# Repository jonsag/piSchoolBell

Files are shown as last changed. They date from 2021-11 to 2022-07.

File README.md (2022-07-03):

# piSchoolBell

This runs a Raspberry Pi as a controller for a school bell.  
It makes the school bell ring at the right times taking the calendar into consideration.  
Also there is an LCD screen to visualize time, database stats, upcoming rings etc.  

Administration of the school bell is done via a web UI.  

It is written entirely in python.  

Also it installs gpio-watch to catch the buttons connected to the Pi's GPIO. [https://github.com/larsks/gpio-watch](https://github.com/larsks/gpio-watch)  

## Updates

### 3/7 -22

Now running on RaspberryPiOS Bullseye.  
Everything updated to run on python3.  
Updated install script.  
Made it easier for those not having the Swedish holidays. (More work needed...)  
New module for printing to LCD.  
Fixed apache not defaulting to index.py.  

### 30/6 -22

The API for Swedish holidays, api.dryg.net, is dead.  
Substituted by [sholiday.faboul.se](https://sholiday.faboul.se/dagar/).  

### 7/3 -20

Changed all GPIO pins to make an easier PCB layout possible.  
This makes all older electric installs incompatible.  
Added KiCad files for new pin layout.  

Corrected editing of ring times.  

### 6/3 -20

Bug discovered  
There was a fault in the database setup.  
Instead of updating, you can:  
Log in to database  
>$ sudo mysql -u root -p piSchoolBell  

Change column type  
>MariaDB [piSchoolBell]> ALTER TABLE ringTimes CHANGE weekDays weekDays VARCHAR(7);  

## Hardware setup

### Parts list

* 1 x Raspberry Pi 3 B+, kjell.com Art#88100 (could be any of the later models)  
* 1 x LCD display, kjell.com Art#90215 (16x2 characters, based on the HD44780 chip)  
* 1 x USB micro power adapter, kjell.com Art#88525  
* 1 x Micro SD card, kjell.com Art#97600  
* 1 x 10k potentiometer, kjell.com Art#90633  
* 1 x 5V relay module, kjell.com Art#87878  
* 4 x Push button, kjell.com Art#36023  
* 4 x 10k resistor  
* 4 x 1k resistor  
* 1 x Switch, kjell.com Art#36016  
* 1 x Casing for rpi, kjell.com Art#89030  
* 1 x Casing for relay, kjell.com Art#89014  
* 1 x RTC-module, kjell.com Art#87984  
* 1 x CR2032 battery, kjell.com ART#33715  
* GPIO header connector, kjell.com Art#87915 (or breakout board)  
* Wiring, cables  
* PCB board, kjell.com Art#89416 or Art#89435 (or a breadboard, just to set it up)  

* Soldering material  

### The build  

Assemble all the parts according to the KiCad files.  

### Install and configure OS

Download RaspberryPiOS Lite from [https://www.raspberrypi.com/software/operating-systems/](https://www.raspberrypi.com/software/operating-systems/).  

Cd to where your download is.  
>$ xz -d 2022-04-04-raspios-bullseye-armhf-lite.img.xz  

Insert SD-card and find out drive letter.  
>$ dmesg  

For example '/dev/mmcblk0' or '/dev/sdb'.  

Unmount if mounted.  
>$ umount /dev/mmcblk0p1  
>$ umount /dev/mmcblk0p2  

Write image to SD-card.  
>$ sudo dd bs=4M if=2022-04-04-raspios-bullseye-armhf-lite.img of=/dev/mmcblk0 conv=fsync status=progress  

Remove SD-card and insert it again to make new partitions visible.  

Mount the first partition.  
>$ sudo mount /dev/mmcblk0p1 /mnt/tmp  

Write empty file to boot partition to enable ssh at boot.  
>$ sudo touch /mnt/tmp/ssh  

Unmount.  
>$ sudo umount /mnt/tmp  

Remove SD-card and insert it in a RPi connected to your local network and boot it up.  

### RPi configuration

For this version of the operating system you should have a monitor and keyboard hooked up at the first boot.  

After some restarts you will start to configure your machine:

* Select keyboard layout  
* Create user and set password. For the sake of this installation it's preferred you set 'pi' as username.  

After this you will have a prompt.  
Find out the ip of the RPi

>$ ifconfig

Connect to the RPi via ssh on another machine (if you don't want to continue as before).  

>$ ssh -ip from above-  -l pi  

Login with the username and password you created earlier  

### Configure

>$ sudo raspi-config  

1 S1    Configure wifi  
2 S4    Change hostname  
4 P2    Set GPU memory to 16  
5 L1    Set locales  
5 L2    Set time zone  
6 A1    Expand file system to use whole SD-card  

Reboot to set new options.  

### Update OS

Connect again  

>$ sudo apt-get update && sudo apt-get upgrade  

## Installation

### Install git

>$ sudo apt-get install git  

### Clone repository

>$ cd /home/pi  
>$ git clone <https://github.com/jonsag/piSchoolBell.git>  

### Run install script

>$ cd /home/pi/piSchoolBell  
>$ sudo ./install.sh  

### Initialize mysql (mariadb)

>$ sudo mysql_secure_installation  

Set root password, and press 'enter' on all other questions

### Create database

>$ sudo /home/pi/piSchoolBell/mysql-setup.sh  

### Add test data, if wanted (otherwise some things will act funny until you create your own entries)  

>$ /home/pi/piSchoolBell/insertTestData.sh  

### Download (Swedish) dates

>$ /home/pi/bin/piSchoolBell/getCalendar.py -v  

### For those living outside of Sweden

If you're not lucky enough to live in Sweden, you can run this to make all weekdays workdays.  

>$ /home/pi/piSchoolBell/makeAllWeekdaysToWorkdays.sh

This includes ALL Mondays to Fridays.  

You will have to manually add your own work free weekdays.  

To set 4'th of July 2023 to work free day (if it wasn't a Sunday already...)  
Connect to mysql  

>$ mysql -u pi -p$(grep password /home/pi/bin/piSchoolBell/mysql-config.ini | awk '{ print $3 }') piSchoolBell
>
>MariaDB [piSchoolBell]> UPDATE days SET isWorkDay = '0' WHERE date = '2023-06-04';

#### Note

In Sweden we use the correct way for dates and numbering days.  

The first day of the week is Monday. It has number '0' in the database.  
When printing dates we use 'YYYY-MM-DD'.  

### Make web pages secure

>$ sudo /home/pi/piSchoolBell/www-secure-setup.sh  

## If you're adding an RTC module

### Enable i2c

>$ sudo raspi-config  

3 I5    Enable I2C interface  

>$ ./install-rtc.sh  

### Set hardware clock

Check that time and date is correct  

>$ date  

Set hardware clock  

>$ sudo hwclock -w  

Comment out the following lines in /lib/udev/hwclock-set  

    if [ -e /run/systemd/system ] ; then  
        exit 0  
    fi  

Reboot  

## Configuration

Press button on unit to display its IP-address on the second line of the LCD.  
Connect to the unit by pointing your browser to  

    http://\<IP-address\>:8080'.  

Edit or add breaks, ring times and ring patterns.  

Remember, you can't really add rings on saturdays or sundays, as this is mainly intended for use on normal school schedules.  

### Automatic tasks

At the first of every month cron will download calendar from 'dryg.net', adding data to the database.  
Every night cron will delete past breaks and days from the database.  

## Usage

Normally the LCD display shows:  
Line 1: HH:MM YYYY-mm-dd, current time and date  
Line 2: HH:MM YYYY-mm-dd, the time and date for the next bell ring  

By pressing button 1, display will show:  
&nbsp;&nbsp;&nbsp;&nbsp;Line 1: days left in db, last date in db  
&nbsp;&nbsp;&nbsp;&nbsp;Line 2: IP-address  
&nbsp;&nbsp;&nbsp;&nbsp;&nbsp;&nbsp;&nbsp;&nbsp;If it shows 'Not connected' it has not been able to acquire an IP address.  
&nbsp;&nbsp;&nbsp;&nbsp;&nbsp;&nbsp;&nbsp;&nbsp;The first character on line 2 shows if the unit can access internet.  
&nbsp;&nbsp;&nbsp;&nbsp;&nbsp;&nbsp;&nbsp;&nbsp;If it is a '*' it is connected.  
&nbsp;&nbsp;&nbsp;&nbsp;&nbsp;&nbsp;&nbsp;&nbsp;If it is a '-' it is not connected.  

Pressing button 2 will make the LCD go back to showing default info.  

## USE THE BELOW WITH CAUTION, NOT TESTED ENOUGH

To dump database and logs to USB-stick:  
Format a stick to fat32 and label it 'PISCHOOLBEL'.  
Insert into Pi.  
&nbsp;&nbsp;&nbsp;&nbsp;Display will show:  
&nbsp;&nbsp;&nbsp;&nbsp;&nbsp;&nbsp;&nbsp;&nbsp;The USBs label and drive letter  
&nbsp;&nbsp;&nbsp;&nbsp;&nbsp;&nbsp;&nbsp;&nbsp;'USB mounted'  
Press button 3.  
&nbsp;&nbsp;&nbsp;&nbsp;Display will confirm writing  
&nbsp;&nbsp;&nbsp;&nbsp;When finished display shows number of files written  

Remove USB  
&nbsp;&nbsp;&nbsp;&nbsp;Display will show:  
&nbsp;&nbsp;&nbsp;&nbsp;&nbsp;&nbsp;&nbsp;&nbsp;drive letter  
&nbsp;&nbsp;&nbsp;&nbsp;&nbsp;&nbsp;&nbsp;&nbsp;'USB umounted'  

Edit the database file with the highest date and time on the stick.  
To read back edited file to database:  
Insert the USB-stick.  
&nbsp;&nbsp;&nbsp;&nbsp;Display will show:  
&nbsp;&nbsp;&nbsp;&nbsp;&nbsp;&nbsp;&nbsp;&nbsp;The USBs label and drive letter  
&nbsp;&nbsp;&nbsp;&nbsp;&nbsp;&nbsp;&nbsp;&nbsp;'USB mounted'  
Press button 4.  
&nbsp;&nbsp;&nbsp;&nbsp;Display will confirm reading  
&nbsp;&nbsp;&nbsp;&nbsp;...  
Not implemented yet.  
For now it only shows how many lines to read back to the database.  

## Issues

If you get problems with Adafruit_Python_CharLCD failing to write to LCD.  

>$ cd /home/pi/piSchoolBell/Adafruit_Python_CharLCD  
>$ sudo python setup.py install  

## Hardware clock / RTC, quick reference

Check system time:  

>$ date  

Check HW-time:  

>$ sudo hwclock -r  

Set HW-clock to system time:  

>$ sudo hwclock -w  

Set system clock from HW-clock:  

>$ sudo hwclock -s  

Set system date manually:  

>$ date +%Y%m%d -s "20120418"  

Set system time manually:  

>$ date +%T -s "11:14:00"  

Set HW-clock manually:  

>$ sudo hwclock --set --date="2011-08-14 16:45:05"  

## Below is only for my own convenience during programming of this project

>$ rsync -raci ~/Documents/EclipseWorkspace/piSchoolBell/* pi@192.168.10.44:/home/pi/bin/piSchoolBell/  
>$ rsync -raci ~/Documents/EclipseWorkspace/piSchoolBell/www/* pi@192.168.10.44:/var/www/piSchoolBell/  
>$ ssh pi@192.168.10.44 'sudo chmod 755 -R /var/www/piSchoolBell'  
>$ ssh pi@192.168.10.44 'sudo chown -R pi:www-data /var/www/piSchoolBell'  
>$ rsync -raci ~/Documents/EclipseWorkspace/piSchoolBell/purgeDatabase.py pi@192.168.10.44:/home/pi/bin/piSchoolBell/  
>
>$ rsync -raci ~/Documents/CodeWorkspace/piSchoolBell pi@192.168.10.99:/home/pi/  
>$ rsync -raci ~/Documents/CodeWorkspace/piSchoolBell/bin/* pi@192.168.10.99:/home/pi/bin/piSchoolBell  

### Things to check after install

>$ list /home/pi/bin/piSchoolBell/  
>$ cat /home/pi/bin/piSchoolBell/gpio.service  
>$ cat /lib/systemd/system/gpio.service  
>$ list /home/pi/bin/piSchoolBell/gpio-scripts  
>$ cat /home/pi/bin/piSchoolBell/gpio-scripts/gpio-script  
>$ list /var/www/piSchoolBell  
>$ cat etc/cron.d/piSchoolBell  
>$ ps ax | grep gpio  

### Run some tests

>$ /home/pi/bin/piSchoolBell/printToLcd.py -v  
>$ i2cdetect -y 1  
>$ cat /proc/driver/rtc

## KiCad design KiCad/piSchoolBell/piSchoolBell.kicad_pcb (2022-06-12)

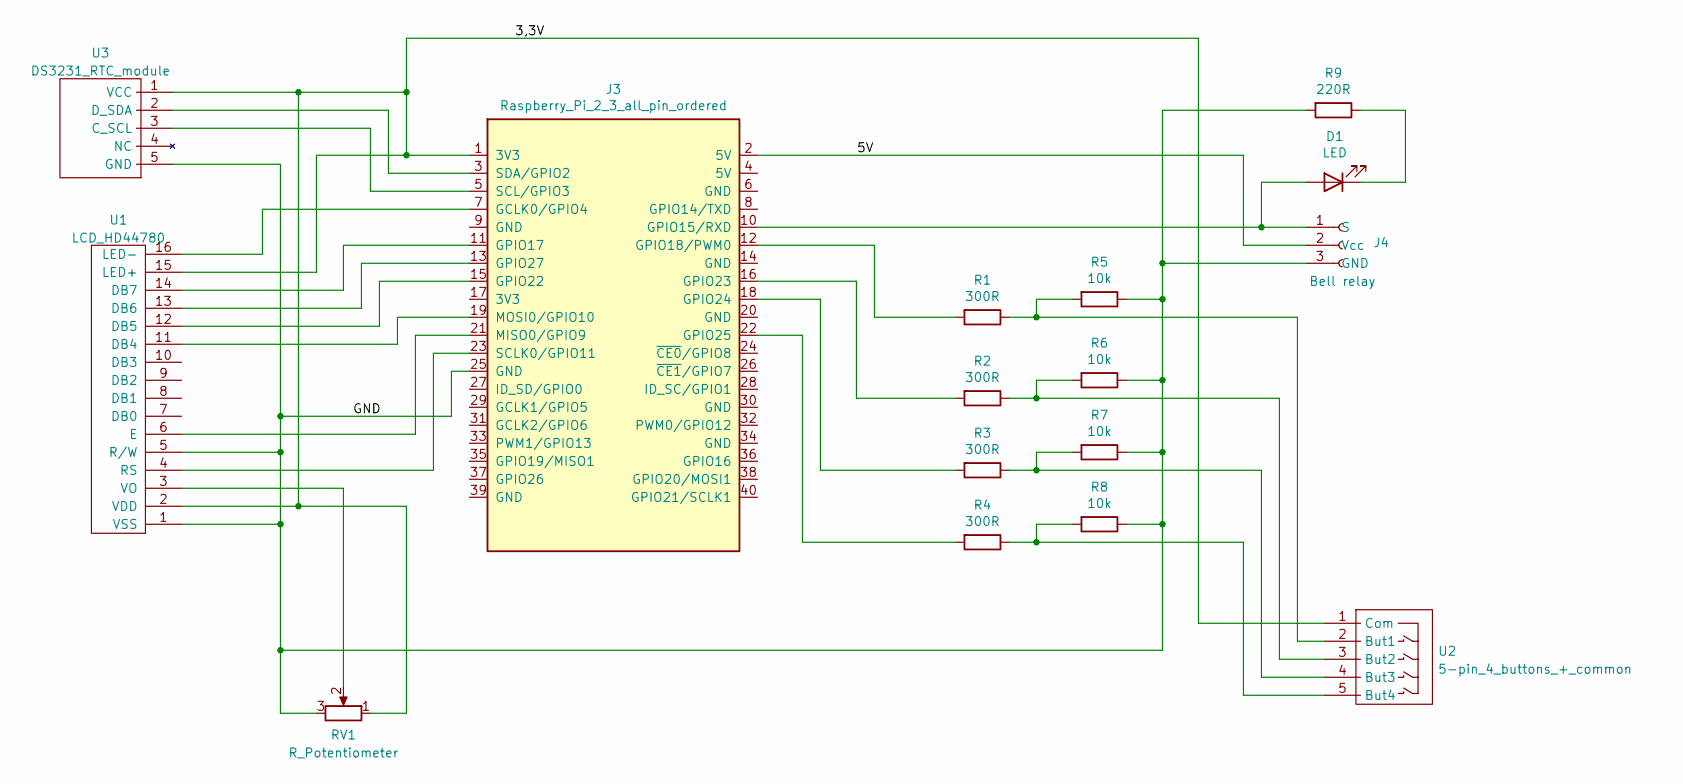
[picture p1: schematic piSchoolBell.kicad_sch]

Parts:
D1: LED; LED_D5.0mm_larger_pads
J3: Raspberry_Pi_2_3_all_pin_ordered; RaspberryPi_3b+_Hat_large
J4: Bell relay; 3-pin JST KY-019 relay
R1, R2, R3, R4: 300R; R_Axial_DIN0207_L6.3mm_D2.5mm_P10.16mm_Horizontal_larger_pa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
R5, R6, R7, R8: 10k; R_Axial_DIN0207_L6.3mm_D2.5mm_P10.16mm_Horizontal_larger_pa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
R9: 220R; R_Axial_DIN0207_L6.3mm_D2.5mm_P10.16mm_Horizontal_larger_pa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
RV1: R_Potentiometer; Potentiometer_Bourns_3339P_Vertical_large
U1: LCD_HD44780; LCD_HD44780_16x2_w_headers_large
U2: 5-pin_4_buttons_+_common; 5-pin JST 4 buttons + common
U3: DS3231_RTC_module; DS3231_RTC_module_large

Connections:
/3,3V: J3.1 (3V3), RV1.1, U1.2 (VDD), U1.15 (LED+), U2.1 (Com), U3.1 (VCC)
/5V: J3.2 (5V), J4.2 (Vcc)
/GND: J3.25 (GND), J4.3 (GND), R5.1, R6.1, R7.1, R8.1, R9.2, RV1.3, U1.1 (VSS), U1.5 (R/W), U3.5 (GND)
unnamed: D1.1 (K), R9.1
unnamed: D1.2 (A), J3.10 (GPIO15/RXD), J4.1 (S)
unnamed: J3.3 (SDA/GPIO2), U3.2 (D_SDA)
unnamed: J3.5 (SCL/GPIO3), U3.3 (C_SCL)
unnamed: J3.7 (GCLK0/GPIO4), U1.16 (LED-)
unnamed: J3.11 (GPIO17), U1.14 (DB7)
unnamed: J3.12 (GPIO18/PWM0), R1.2
unnamed: J3.13 (GPIO27), U1.13 (DB6)
unnamed: J3.15 (GPIO22), U1.12 (DB5)
unnamed: J3.16 (GPIO23), R2.2
unnamed: J3.18 (GPIO24), R3.2
unnamed: J3.19 (MOSI0/GPIO10), U1.11 (DB4)
unnamed: J3.21 (MISO0/GPIO9), U1.6 (E)
unnamed: J3.22 (GPIO25), R4.2
unnamed: J3.23 (SCLK0/GPIO11), U1.4 (RS)
unnamed: R1.1, R5.2, U2.2 (But1)
unnamed: R2.1, R6.2, U2.3 (But2)
unnamed: R3.1, R7.2, U2.4 (But3)
unnamed: R4.1, R8.2, U2.5 (But4)
unnamed: RV1.2, U1.3 (VO)

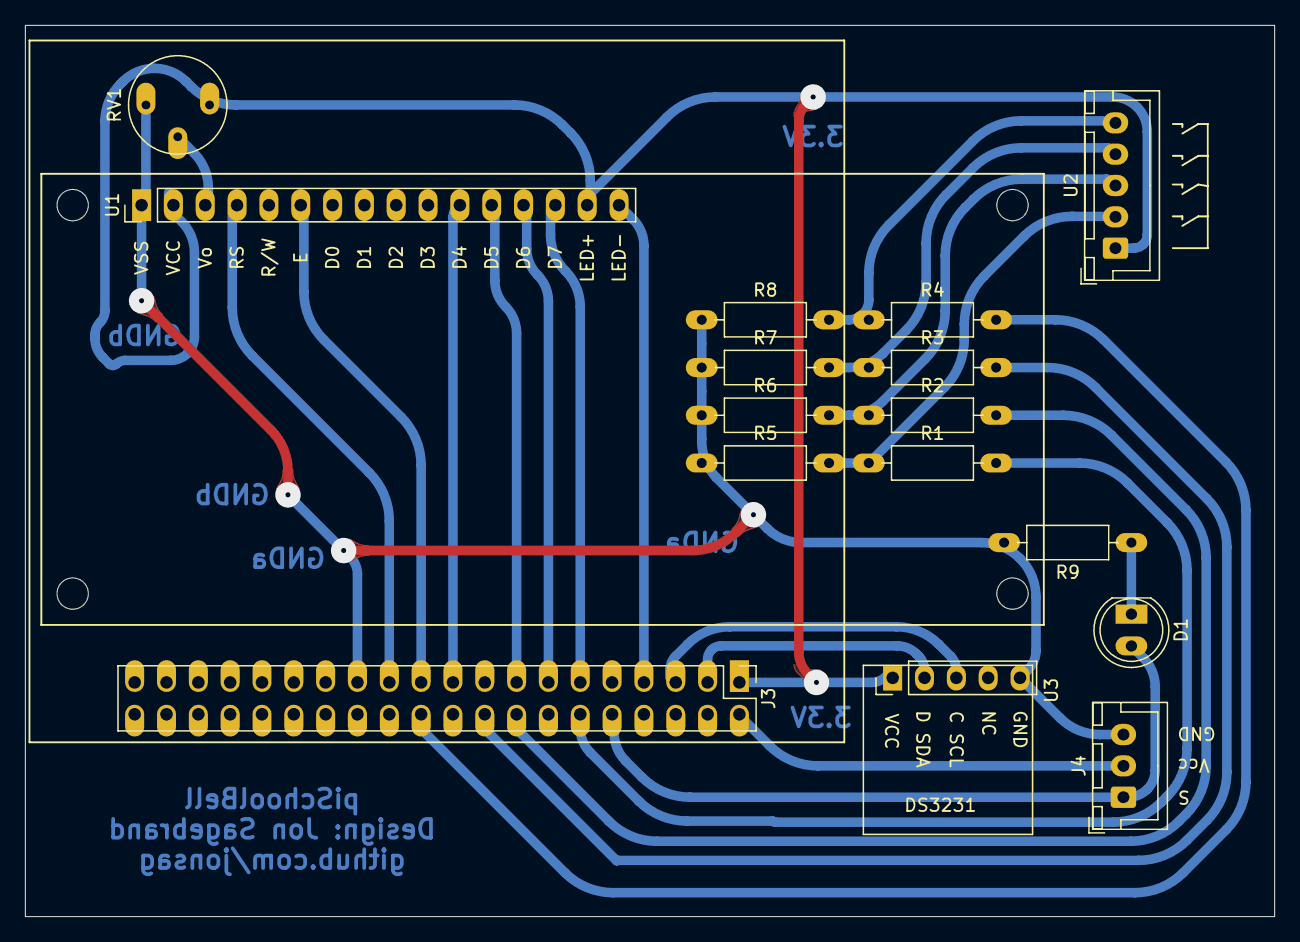
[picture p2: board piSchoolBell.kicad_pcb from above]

Board: 2 copper layers, 99.7 x 71.1 mm, 16 parts (0 on the bottom side), 23 nets.

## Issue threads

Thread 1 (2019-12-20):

Resistor values

ka8nbg, 2019-12-20:
Real quick question, I see you are using 4 1k and 4 10k resistors, but the drawing shows the same color code for all 8. Which ones need to go to where? Is it documented somewhere?  Thanks in advanced.

jonsag, 2019-12-20:
Actually, of you look carefully on the fritz the restistors are different coloured.
The ones to the left of each switch are brown/black/red, and the ones to the right are  brown/black/orange.
So the order should be:
VCC-->10k-->switch-->1k-->input
and the other switch leg goes straight to GND.
If you want you can actually skip the 1k resistors. These are just for protection.
The 10k are pullups.
Good luck
/jon

ka8nbg, 2019-12-20:
Wow, I am getting more and more color blind.  Thanks for the
clarification!!!!   Plan on getting this built this weekend.  Have a great
Christmas!!!!

On Fri, Dec 20, 2019 at 11:15 AM Jon Sagebrand <notifications@github.com>
wrote:

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

jonsag, 2019-12-20:
It was a little hard to see. Wasn't sure myself until I clicked the components in the real fritz.
Are you planning to use it in a school? I have mine running in the school where I work. The old mechanical clock was running five-ten minutes fast every day and too expensive to repair.
Happy christmas for you too.
/jon

ka8nbg, 2019-12-21:
Yes, our church just started at school this past semester and was looking for an outside bill. I’m looking to get this up and running this next week and installed. We bought one of those fire alarm bells that runs on 110 VAC. By the way, you mentioned about a PC board that you have for this project, do you still have more of those? I have a real issue with creating breadboards and never getting them converted over, If you know what I mean. Here’s an example of one lesson production. Not very proud of the final product but it works very well.

Sent from my iPhone

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

jonsag, 2019-12-21:
I soldered it up on an experiment board and this is how it runs now.
Didn't make a PCB for this. Started out making one in Eagle CAD, but never finished with the routing. You can now find it in the 'Documents' directory if you would like to finish it.
For some of my projects I have ordered PCBs from jlcpcb.com. 10 boards for $2+shipping! Reasonably fast shipping and good finish.

jonsag, 2019-12-21:
Did some routing on the Eagle files in documentation and uploaded a Gerber-file for ordering PCBs.
Of course not tested, and perhaps you can do a better job.
Also added etching masks if you would like to make some PCBs yourself.

ka8nbg, 2019-12-22:
Awesome. Will take a look at it. Thanks again.

On Sat, Dec 21, 2019 at 4:10 PM Jon Sagebrand <notifications@github.com>
wrote:

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

ka8nbg, 2019-12-23:
Jon, I have installed the OS and the software from the GIT repository. Have
it configured, have not been able to log into the web page using
piSchoolBell and the password that I created. Any idea what I am missing?

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

jonsag, 2019-12-27:
Sorry for the late reply. The holidays and all you know...
You ran 'www-secure-setup.sh'?
OK, temporarily comment out the four lines:
AuthName "piSchoolBell"
AuthType Basic
AuthUserFile /home/pi/bin/piSchoolBell/.htpasswd
require valid-user
in '/var/www/piSchoolBell/.htaccess'
Can you load the pages now?
If yes, then uncomment them.
Try to add another user:
`sudo htpasswd -c /home/pi/bin/piSchoolBell/.htpasswd`
Now try to login with that user

Closed 2019-12-20.

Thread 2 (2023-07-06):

username and password to access web interface.

DanielProwse, 2023-07-06:
Hi

I am wanting to confirm what the username and password should be to access the web interface localhost:8080?

I have tried the db user but it is not authenticating.

Hope you can help.

ka8nbg, 2023-07-06:
Thanks for the reply. I ended up using something else, but will look into
going back to this.  Thanks.

On Thu, Jul 6, 2023 at 3:30 AM Jon Sagebrand ***@***.***>
wrote:

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

Closed 2023-07-06.

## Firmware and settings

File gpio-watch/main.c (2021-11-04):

/*
 * gpio-watch, a tool for running scripts in response to gpio events
 * Copyright (C) 2014 Lars Kellogg-Stedman <lars@oddbit.com>
 *
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
 * You should have received a copy of the GNU General Public License
 * along with this program.  If not, see <http://www.gnu.org/licenses/>.
 */

#include <fcntl.h>
#include <getopt.h>
#include <poll.h>
#include <stdio.h>
#include <stdlib.h>
#include <string.h>
#include <sys/wait.h>
#include <time.h>
#include <unistd.h>

#include "gpio.h"
#include "fileutil.h"
#include "logging.h"

#define OPTSTRING "s:e:vdl:"

#define OPT_SCRIPT_DIR 's'
#define OPT_DEFAULT_EDGE 'e'
#define OPT_VERBOSE 'v'
#define OPT_LOGFILE 'l'
#define OPT_DETACH 'd'

// Where to look for event scripts.  Scripts in this directory
// must be named after the pin number being monitored (so,
// for example, /etc/gpio-scripts/4).
#ifndef DEFAULT_SCRIPT_DIR
#define DEFAULT_SCRIPT_DIR "/etc/gpio-scripts"
#endif

// use for converting seconds to nanoseconds.
#define NANOS 1000000000LL
#define DEBOUNCE_INTERVAL 100000L

char *script_dir = DEFAULT_SCRIPT_DIR;
char *logfile = NULL;
int default_edge = EDGE_BOTH;
int detach = 0;

// This will hold the list of pins to monitor generated from
// command line arguments.
struct pin *pins = NULL;
int num_pins = 0;

void usage(FILE *out)
{
	fprintf(out, "gpio-watch: usage: gpio-watch [-l logfile] [-s script_dir] [-e default_edge] [-dv] pin[:edge] [...]\n");
}

// Run a script in response to an event.
void run_script(int pin, int value)
{
	char *script_path,
		pin_str[GPIODIRLEN],
		value_str[2];
	int script_path_len;
	pid_t pid;
	int status;

	script_path_len = strlen(script_dir) + GPIODIRLEN + 2;
	script_path = (char *)malloc(script_path_len);

	snprintf(script_path, script_path_len,
			 "%s/%d", script_dir, pin);

	if (!is_file(script_path))
	{
		LOG_WARN("pin %d: script \"%s\" does not exist",
				 pin, script_path);
		return;
	}

	snprintf(pin_str, GPIODIRLEN, "%d", pin);
	sprintf(value_str, "%d", value);

	LOG_INFO("pin %d: running script %s", pin, script_path);

	if (0 == (pid = fork()))
	{
		int res;
		res = execl(script_path, script_path, pin_str, value_str, (char *)NULL);
		if (-1 == res)
			exit(255);
	}

	wait(&status);

	if (WIFEXITED(status))
	{
		if (0 != WEXITSTATUS(status))
		{
			LOG_WARN("pin %d: event script exited with status = %d",
					 pin, WEXITSTATUS(status));
		}
	}
	else if (WIFSIGNALED(status))
	{
		LOG_WARN("pin %d: event script exited due to signal %d",
				 pin, WTERMSIG(status));
	}

	free(script_path);
}

// Loop forever monitoring pins for activity.
int watch_pins()
{
	struct pollfd *fdlist;
	int i;
	char *pin_path;
	int pin_path_len;
	char valbuf[3];
	struct timespec ts;

	unsigned char switch_state[num_pins];
	long long now,
		down_at[num_pins];

	valbuf[2] = '\0';
	memset(switch_state, 0, num_pins);

	pin_path_len = strlen(GPIO_BASE) + GPIODIRLEN + strlen("value") + 3;
	pin_path = (char *)malloc(pin_path_len);

	fdlist = (struct pollfd *)malloc(sizeof(struct pollfd) * num_pins);
	for (i = 0; i < num_pins; i++)
	{
		int fd;

		snprintf(pin_path, pin_path_len,
				 "%s/gpio%d/value", GPIO_BASE, pins[i].pin);
		fd = open(pin_path, O_RDONLY);
		read(fd, valbuf, 2);
		fdlist[i].fd = fd;
		fdlist[i].events = POLLPRI;
	}

	LOG_INFO("starting to monitor for gpio events");

	while (1)
	{
		int err;

		err = poll(fdlist, num_pins, -1);
		if (-1 == err)
		{
			perror("poll");
			exit(1);
		}

		for (i = 0; i < num_pins; i++)
		{
			if (fdlist[i].revents & POLLPRI)
			{
				LOG_DEBUG("pin %d: received event",
						  pins[i].pin);
				lseek(fdlist[i].fd, 0, SEEK_SET);
				read(fdlist[i].fd, valbuf, 2);

				// for pins use 'switch' edge mode, we only trigger
				// an event when we receive the '1' event more than
				// DEBOUNCE_INTERVAL nanoseconds after the '0' event.
				if (EDGE_SWITCH == pins[i].edge)
				{
					clock_gettime(CLOCK_MONOTONIC, &ts);
					now = ts.tv_sec * NANOS + ts.tv_nsec;

					if (switch_state[i] == 0 && valbuf[0] == '1')
					{
						down_at[i] = now;
						switch_state[i] = 1;
					}
					else if (switch_state[i] == 1 && valbuf[0] == '0')
					{
						if (now - down_at[i] > DEBOUNCE_INTERVAL)
						{
							switch_state[i] = 0;
							goto run_script;
						}
					}

					continue;
				}

			run_script:
				run_script(pins[i].pin,
						   valbuf[0] == '1' ? 1 : 0);
			}
		}
	}
}

int main(int argc, char **argv)
{
	struct pollfd *fdlist;
	int numfds = 0;
	int ch;
	int i;

	while (-1 != (ch = getopt(argc, argv, OPTSTRING)))
	{
		switch (ch)
		{
		case OPT_LOGFILE:
			logfile = strdup(optarg);
			break;
		case OPT_DETACH:
			detach = 1;
			break;
		case OPT_SCRIPT_DIR:
			script_dir = strdup(optarg);
			break;
		case OPT_DEFAULT_EDGE:
			if (-1 == (default_edge = parse_edge(optarg)))
			{
				fprintf(stderr, "error: invalid edge value: %s\n", optarg);
				exit(1);
			}
			break;
		case OPT_VERBOSE:
			loglevel += 1;
			break;

		case '?':
			usage(stderr);
			exit(2);
		}
	}

	if (logfile)
	{
		int fd;
		if (-1 == (fd = open(logfile, O_WRONLY | O_CREAT | O_APPEND, 0644)))
		{
			LOG_ERROR("failed to open logfile %s", logfile);
			exit(1);
		}

		close(1);
		close(2);

		dup(fd);
		dup(fd);
	}

	if (!is_dir(script_dir))
	{
		LOG_ERROR("error: script directory \"%s\" does not exist.",
				  script_dir);
		exit(1);
	}

	for (i = optind; i < argc; i++)
	{
		char *pos,
			*pinspec;
		struct pin p;

		pinspec = strdup(argv[i]);
		pos = strchr(pinspec, ':');

		if (pos)
		{
			*pos = '\0';
			pos++;
			p.pin = atoi(pinspec);
			if (-1 == (p.edge = parse_edge(pos)))
			{
				fprintf(stderr, "error: unknown edge spec: %s\n",
						argv[i]);
				exit(1);
			}
		}
		else
		{
			p.pin = atoi(pinspec);
			p.edge = default_edge;
		}

		free(pinspec);

		num_pins++;
		pins = realloc(pins, sizeof(struct pin) * num_pins);
		pins[num_pins - 1] = p;
	}

	for (i = 0; i < num_pins; i++)
	{
		pin_export(pins[i].pin);
		pin_set_edge(pins[i].pin, pins[i].edge);
		pin_set_direction(pins[i].pin, DIRECTION_IN);
	}

	if (detach)
		daemon(1, logfile ? 1 : 0);

	watch_pins();

	return 0;
}

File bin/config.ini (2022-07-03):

[lcd]
# Raspberry Pi pin configuration, GPIO numbers
# lcd_rs				LCD pin 4	Register Select (RS). RS=0: Command, RS=1: Data
# lcd_en				LCD pin 6	Clock (Enable). Falling edge triggered
# lcd_d4				LCD pin 11	Bit 4
# lcd_d5				LCD pin 12	Bit 5
# lcd_d6				LCD pin 13	Bit 6
# lcd_d7				LCD pin 14	Bit 7
# lcd_backlight = 5		LCD pin 15	Backlight LED Anode (+) (not used in this setup

					# old GPIO
lcd_rs        = 11	# 20, pin 38
lcd_en        = 9	# 21, pin 21
lcd_d4        = 10	# 6, pin 19
lcd_d5        = 22	# 13, pin 33
lcd_d6        = 27	# 19, pin 35
lcd_d7        = 17	# 26, pin 11
lcd_backlight = 4	# 5, pin 29

# Define LCD column and row size
lcd_columns = 16
lcd_rows    = 2

# Define time the LCD will be illuminated after each action, whole seconds
lcd_wake_time = 5

[gpioAssignment]
bellRelayGpio = 15

					# old GPIO
button1Gpio = 18	# 7, pin 26
button2Gpio = 23	# 8, pin 24
button3Gpio = 24	# 9, pin 21
button4Gpio = 25	# 10, pin 19

[misc]
# degree sign
unicode_degree_sign = u'\u00b0'

# this is the estimated boot time in seconds
minUptime = 60

# how long until retry to get ip
ipWaitTime = 1

# the address we look up on internet
testAddress = www.google.com

[paths]
logFile = /home/pi/bin/piSchoolBell/piSchoolBell.log

tempDir = /home/pi/bin/piSchoolBell/tmp

USBDir = /media
labelMatch = piSchoolBel

gpioWatchLog = /home/pi/bin/piSchoolBell/gpio-watch.log

[dryg]
# dryg's api is now dead
#drygUri = https://api.dryg.net
#drygPath = dagar/v2.1

# a working fork is hosted at faboul.se
drygUri = https://sholiday.faboul.se
drygPath = dagar/v2.1

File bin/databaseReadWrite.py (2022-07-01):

#!/usr/bin/env python3
# -*- coding: utf-8 -*-
# Encoding: UTF-8

import sys, getopt, os

from datetime import datetime
from shutil import copy, copyfile

from modules import (
    db_connect,
    db_create_cursor,
    db_close_cursor,
    db_disconnect,
    db_query,
    tempDir,
    USBDir,
    labelMatch,
    findUSBMountPoint,
    logFile,
    gpioWatchLog,
    splitPath,
    displayOnLCD,
    tableSelection,
    onError,
    usage,
)

try:
    myopts, args = getopt.getopt(
        sys.argv[1:], "dr" "vh", ["dump", "read", "verbose", "help"]
    )

except getopt.GetoptError as e:
    onError(1, str(e))

# if len(sys.argv) == 1:  # no options passed
#    onError(2, 2)

dump = False
read = False
verbose = False

for option, argument in myopts:
    if option in ("-d", "--dump"):  # first line of LCD
        dump = True
    elif option in ("-r", "--read"):  # verbose output
        read = True
    elif option in ("-v", "--verbose"):  # verbose output
        verbose = True
    elif option in ("-h", "--help"):  # display help text
        usage(0)

if dump and read:
    onError(3, "You cannot state both '-d' ('--dump') and -r' ('--read')")


def dumpToFile():
    filesWritten = 0

    timeNow = datetime.today()
    timeStamp = timeNow.strftime("%Y%m%d%H%M%S")

    USBPath = findUSBMountPoint(USBDir, labelMatch, verbose)

    if not USBPath:
        LCDMessage = "No USB inserted"

        if verbose:
            print("\n*** Printing to LCD: \n    %s" % LCDMessage)
        displayOnLCD("", LCDMessage, verbose)
        onError(5, "No matching USB mounted")
    else:
        displayOnLCD("", "Writing files...", verbose)

    # database
    outFilePath = os.path.join(tempDir, "piSchoolBellDb-%s.csv" % timeStamp)

    if verbose:
        print("\n*** Creating file %s ..." % outFilePath)
    outFile = open(outFilePath, "a")

    # connect to database
    cnx = db_connect(verbose)

    # create cursor
    cursor = db_create_cursor(cnx, verbose)

    for table in ("breaks", "ringTimes", "ringPatterns", "days"):
        if verbose:
            print("\n*** Reading table %s..." % table)

        selection = tableSelection(table, verbose)

        query = "SELECT " + selection + " FROM " + table + " "
        result, rowCount = db_query(cursor, query, verbose)  # run query

        if rowCount:
            if verbose:
                print("\n*** Table: %s" % table)

            columnNames = selection.replace(", ", ";")
            outFile.write("%s;%s\n" % (table, columnNames))

            selection = selection.replace(" ", "").split(",")

            for row in result:
                i = 0
                values = ""

                for columnName in selection:
                    column = row[i]
                    values = "%s;%s" % (values, column)

                    if verbose:
                        print("    %s: %s" % (columnName, column))

                    i += 1

                outFile.write("%s\n" % values)

                if verbose:
                    print()

    if verbose:
        print("\n*** Closing file %s ..." % outFilePath)
    outFile.close()

    if verbose:
        print("\n*** Moving file \n    %s \n    to \n    %s" % (outFilePath, USBPath))

    copy(outFilePath, USBPath)
    filesWritten += 1

    # log files
    dirName, fileName, extension = splitPath(logFile, verbose)

    logFileName = os.path.join(USBPath, "%s-%s.%s" % (fileName, timeStamp, extension))

    if verbose:
        print("\n*** Copying \n    %s \n    to \n    %s ..." % (logFile, logFileName))

    copyfile(logFile, logFileName)
    filesWritten += 1

    if verbose:
        print("    %s" % gpioWatchLog)

    dirName, fileName, extension = splitPath(gpioWatchLog, verbose)

    gpioWatchLogName = os.path.join(
        USBPath, "%s-%s.%s" % (fileName, timeStamp, extension)
    )

    if verbose:
        print(
            "\n*** Copying \n    %s \n    to \n    %s ..."
            % (
                gpioWatchLog,
                gpioWatchLogName,
            )
        )

    copyfile(gpioWatchLog, gpioWatchLogName)
    filesWritten += 1

    # close cursor
    db_close_cursor(cnx, cursor, verbose)

    # close db
    db_disconnect(cnx, verbose)

    LCDMessage = "%s files written" % filesWritten

    if verbose:
        print("\n*** Printing to LCD: \n    %s" % LCDMessage)

    displayOnLCD("", LCDMessage, verbose)


def readFromFile():
    timeNow = datetime.today()
    timeStamp = timeNow.strftime("%Y%m%d%H%M%S")

    USBPath = findUSBMountPoint(USBDir, labelMatch, verbose)
    if not USBPath:
        LCDMessage = "No USB inserted"
        if verbose:
            print("\n*** Printing to LCD: \n    %s" % LCDMessage)
        displayOnLCD("", LCDMessage, verbose)
        onError(4, "No matching USB mounted")
    else:
        displayOnLCD("", "Reading files...", verbose)

    if verbose:
        print("\n*** Searching for files in %s ..." % USBDir)

    foundFiles = []
    for f in os.listdir(USBPath):
        if f.startswith("piSchoolBellDb-") and f.endswith(".csv"):
            foundFiles.append(os.path.join(USBPath, f))

    if foundFiles:
        if verbose:
            print("    %s files found:" % len(foundFiles))
            for f in foundFiles:
                print("    %s" % f)

        foundFiles = sorted(foundFiles, reverse=True)
        inFile = foundFiles[0]

        if verbose:
            print("\n*** %s\n    is the latest" % inFile)

        rowsInserted, rowsUpdated = importToDb(
            inFile, verbose
        )  # import from file to database

        if rowsInserted:
            if verbose:
                print("\n*** %s rows inserted" % rowsInserted)
        else:
            if verbose:
                print("\n*** Nothing inserted")

        if rowsUpdated:
            if verbose:
                print("\n*** %s rows updated" % rowsUpdated)
        else:
            if verbose:
                print("\n*** Nothing updated")

        displayOnLCD("", "%s rows inserted" % rowsInserted, verbose)

    else:
        if verbose:
            print("*** No file found")

        displayOnLCD("", "No file found", verbose)

        sys.exit(0)
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

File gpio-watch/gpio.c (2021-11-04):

/*
 * gpio-watch, a tool for running scripts in response to gpio events
 * Copyright (C) 2014 Lars Kellogg-Stedman <lars@oddbit.com>
 *
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
 * You should have received a copy of the GNU General Public License
 * along with this program.  If not, see <http://www.gnu.org/licenses/>.
 */

#include <stdio.h>
#include <stdlib.h>
#include <unistd.h>
#include <string.h>

#include "gpio.h"
#include "fileutil.h"
#include "logging.h"

// Parse a string ("in", "out") and return
// the corresponding DIRECTION_* constant, or -1 if the string
// is invalid.
int parse_direction(const char *direction)
{
	if (0 == strncmp(direction, "in", DIRSTRLEN))
		return DIRECTION_IN;
	else if (0 == strncmp(direction, "out", DIRSTRLEN))
		return DIRECTION_OUT;
	else
		return -1;
}

// Parse a string ("rising", "falling", "both") and return
// the corresponding EDGE_* constant, or -1 if the string
// is invalid.
int parse_edge(const char *edge)
{
	if (0 == strncmp(edge, "rising", EDGESTRLEN))
		return EDGE_RISING;
	else if (0 == strncmp(edge, "falling", EDGESTRLEN))
		return EDGE_FALLING;
	else if (0 == strncmp(edge, "both", EDGESTRLEN))
		return EDGE_BOTH;
	else if (0 == strncmp(edge, "switch", EDGESTRLEN))
		return EDGE_SWITCH;
	else if (0 == strncmp(edge, "none", EDGESTRLEN))
		return EDGE_NONE;
	else
		return -1;
}

// Export a pin by writing to /sys/class/gpio/export.
void pin_export(int pin)
{
	char *export_path,
		*pin_path;
	int export_path_len,
		pin_path_len;

	LOG_DEBUG("pin %d: exporting", pin);

	export_path_len = strlen(GPIO_BASE) + strlen("export") + 3;
	export_path = (char *)malloc(export_path_len);
	snprintf(export_path, export_path_len - 1, "%s/export", GPIO_BASE);

	pin_path_len = strlen(GPIO_BASE) + GPIODIRLEN + 3;
	pin_path = (char *)malloc(pin_path_len);
	snprintf(pin_path, pin_path_len - 1, "%s/gpio%d", GPIO_BASE, pin);

	if (!is_dir(pin_path))
	{
		FILE *fp;
		int tries = 0;

		fp = fopen(export_path, "w");
		if (!fp)
		{
			LOG_ERROR("pin %d: failed to open %s: cannot export",
					  pin, export_path);
		}
		fprintf(fp, "%d\n", pin);
		fclose(fp);

		// gpio directories are initially owned by 'root'.  If you have
		// udev rules that change this, it may take a moment for those
		// changes to happen.
		LOG_DEBUG("waiting for udev to catch up");
		sleep(1);
	}

end:
	free(pin_path);
	free(export_path);
}

// Set which signal edges to detect.
int pin_set_edge(int pin, int edge)
{
	char *pin_path;
	int pin_path_len;
	FILE *fp;

	LOG_DEBUG("pin %d: setting edge mode %d", pin, edge);

	pin_path_len = strlen(GPIO_BASE) + GPIODIRLEN + strlen("edge") + 4;
	pin_path = (char *)malloc(pin_path_len);
	snprintf(pin_path, pin_path_len - 1,
			 "%s/gpio%d", GPIO_BASE, pin);

	if (!is_dir(pin_path))
	{
		LOG_ERROR("pin %d: not exported.", pin);
		exit(1);
	}

	snprintf(pin_path, pin_path_len,
			 "%s/gpio%d/edge", GPIO_BASE, pin);

	fp = fopen(pin_path, "w");
	if (!fp)
	{
		LOG_ERROR("pin %d: failed to open %s: unable to set edge",
				  pin, pin_path);
		exit(1);
	}

	if (EDGE_RISING == edge)
		fprintf(fp, "rising\n");
	else if (EDGE_FALLING == edge)
		fprintf(fp, "falling\n");
	else if (EDGE_BOTH == edge || EDGE_SWITCH == edge)
		fprintf(fp, "both\n");
	else
	{
		LOG_ERROR("pin %d: invalid edge mode (%d)",
				  pin, edge);
		exit(1);
	}

	fclose(fp);
	free(pin_path);
}

// Set pin as input or output.
int pin_set_direction(int pin, int direction)
{
	char *pin_path;
	int pin_path_len;
	FILE *fp;

	LOG_DEBUG("pin %d: setting direction %d", pin, direction);

	pin_path_len = strlen(GPIO_BASE) + GPIODIRLEN + strlen("direction") + 3;
	pin_path = (char *)malloc(pin_path_len);
	snprintf(pin_path, pin_path_len,
			 "%s/gpio%d", GPIO_BASE, pin);

	if (!is_dir(pin_path))
	{
		LOG_ERROR("pin %d: not exported.", pin);
		exit(1);
	}

	snprintf(pin_path, pin_path_len,
			 "%s/gpio%d/direction", GPIO_BASE, pin);

	fp = fopen(pin_path, "w");
	if (DIRECTION_IN == direction)
		fprintf(fp, "in\n");
	else if (DIRECTION_OUT == direction)
		fprintf(fp, "out\n");
	else
	{
		LOG_ERROR("pin %d: invalid direction (%d)",
				  pin, direction);
		exit(1);
	}

	fclose(fp);
	free(pin_path);
}

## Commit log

2018-03-06 Now gets and inserts school days i db
2018-03-07 Now rings bell at correct times and dates
    [getCalendar.py, modules.py, printToLcd.py]
2018-03-12 Prints IP to LCD when pressing button
2018-03-16 Added Documents
    [piSchoolBell.fzz]
2018-03-18 Added scripts for auto mounting USB. Added uninstall.
2018-03-19 Now prints to LCD on USB insertion/removal
2018-04-17 Added two more buttons
2018-04-18 Added and deleted files. Updated fritzing
    [piSchoolBell.fzz]
2018-04-18 Updated fritz
    [piSchoolBell.fzz]
2019-12-21 Added Eagle schematics
    [piSchoolBell-12pinLCD.brd, piSchoolBell-12pinLCD.sch, piSchoolBell.fzz]
2019-12-21 Routed PCB
    [piSchoolBell-12pinLCD.brd, piSchoolBell-12pinLCD.sch]
2019-12-21 Coppper pour on pdfs
    [piSchoolBell-12pinLCD.brd, piSchoolBell-12pinLCD.sch]
2020-03-02 restored file that was deleted by mistake
    [modules.py]
2020-03-06 fixes bug in database setup
    [modules.py, ringBell.py]
2020-03-07 new GPIO pins, eagle cad no longer relevant
    [config.ini]
2020-03-07 all new pin layout, check README!
    [piSchoolBell.kicad_pcb, piSchoolBell.sch]
2020-03-08 moved pin for backlight in KiCad
    [piSchoolBell.kicad_pcb, piSchoolBell.sch]
2022-06-12 minor schematic change
    [piSchoolBell.kicad_pcb, piSchoolBell.kicad_sch]
2022-07-01 deleted Eagle and Fritzing
    [piSchoolBell-12pinLCD.brd, piSchoolBell-12pinLCD.sch, piSchoolBell.fzz]

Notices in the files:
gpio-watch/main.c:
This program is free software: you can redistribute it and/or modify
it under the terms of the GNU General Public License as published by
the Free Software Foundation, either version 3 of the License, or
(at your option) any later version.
